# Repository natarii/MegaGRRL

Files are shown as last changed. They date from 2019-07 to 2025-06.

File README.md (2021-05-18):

MegaGRRL - Real Hardware Sega Genesis VGM Player
========
**MegaGRRL** is an ESP32-powered VGM player, playing tracks from the Sega Mega Drive/Genesis, Master System, and more on real YM2612 and SN76489 sound chips.

## Overview
MegaGRRL is a system comprised of ESP32-powered hardware to interface with original YM2612 and SN76489 sound chips, and FreeRTOS-based firmware using the ESP-IDF framework. Its playback engine is focused on high accuracy and supporting as many features of the VGM file format as possible. It is a completely standalone player, requiring no connection to a host PC. MegaGRRL OS has a fully-featured, easy to use UI, and several unique features which make it the premier hardware playback solution.

There are currently two main hardware versions. The same firmware targets both.
  * **MegaGRRL Desktop**
  * **MegaGRRL Portable** (still in development)

The MegaGRRL Desktop hardware also supports the following **MegaMods** allowing sound chips other than the YM2612/SN76489 to be used:
  * **OPNA MegaMod** - Uses the OPNA (YM2608). Can also play VGMs for OPN (YM2203) and AY-3-8910.
  * **OPL3 MegaMod** - Uses the OPL3 (YMF262). Can also play VGMs for OPL2 (YM3812) and OPL (YM3526).

This repository contains the MegaGRRL OS firmware, and includes the hardware as submodules. Use `--recursive` when cloning the repo to get the hardware files as well.

  * **esp-idf-patches/** - ESP-IDF v3.3.4 SPI master driver patches, required for build
  * **hardware/** - Hardware files for all base board versions, and MegaMods for the Desktop version
  * **firmware/** - Firmware for the ESP32
  * **utils/** - Utilities, such as for packing firmware updates

## Compiling and initial flash
  * Windows users: A complete guide is available [here](https://git.agiri.ninja/snippets/3).
  * Other platforms: MegaGRRL OS is built like a standard ESP-IDF v3.3.4 project, but some patches are required. Please see [doc/compiling.md](https://git.agiri.ninja/natalie/megagrrl/-/blob/master/doc/compiling.md) for more information.

## Updating firmware
To update to the latest firmware after your player is up and running, download the latest .mgu file for your hardware version (desktop or portable) from the [Releases page](https://git.agiri.ninja/natalie/megagrrl/-/releases) and copy it to the SD card. Launch the update from MegaGRRL's file browser.

## Obtaining VGM files
The defacto standard Genesis/Mega Drive VGM repository is [Project 2612](https://project2612.org/). Both .vgm and .vgz files are supported, but load times are shorter if using vgm. VGMs for other sound chips can be obtained from [VGMRips](https://vgmrips.net/packs/).

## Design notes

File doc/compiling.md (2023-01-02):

## Compiling and initial flash
0. If you are on Windows and flashing a MegaGRRL Desktop, a simplified guide is available [here](https://git.agiri.ninja/snippets/3). Otherwise, proceed with the instructions below.
1. Set up ESP-IDF v3.3.4 following the [Espressif documentation](https://docs.espressif.com/projects/esp-idf/en/v3.3.4/get-started/index.html).
2. Clone the repo
   - `cd ~`
   - `git clone https://git.agiri.ninja/natalie/megagrrl`
   - `cd megagrrl`
   - `git tag` <- find the latest version
   - `git checkout v0.00` <- use the latest version number here
3. Apply the patches contained in `esp-idf-patches/`.
   - `patch $IDF_PATH/components/driver/spi_master.c spi_master.c.patch`
   - `patch $IDF_PATH/components/driver/include/driver/spi_master.h spi_master.h.patch`
   - If you are on Windows and using Espressif's MSYS2 setup, you will need to install patch using `pacman -S patch`
4. Uncomment `#define FWUPDATE` in `firmware/main/hal.h`, and ensure the correct hardware version is uncommented.
5. Connect the MegaGRRL's UART to your computer. Ensure the SD card D2 pullup resistor is not populated (R999 on portable, RN2 on desktop), and no SD card is inserted.
6. Burn the 3.3 volt flash efuse using `$IDF_PATH/components/esptool_py/esptool/espefuse.py set_flash_voltage 3.3V`.
7. `make flash`. The firmware updater is now installed on the ESP32.
8. If MegaGRRL's display appears sideways and corrupted, you will need to select an alternate LCD in `hal.h`.
9. Re-comment `#define FWUPDATE`.
10. `make all`.
11. Format an SD card as FAT32, then find the `megagrrl.bin` file in `firmware/build/`, rename it to `factory.mgf`, and copy it to the root of the card.
12. Populate the SD card D2 pullup resistor.
13. Insert the card into the MegaGRRL and power it on. The firmware will now self-flash, and reboot into the OS.

Note: If the default serial device (`/dev/ttyUSB0`) doesn't work on your machine, you may need to set it manually using the `--port` option (for Python scripts) or the `ESPPORT` environment variable (for `make`). On macOS, for example, the device path may take the form of `/dev/cu.usbserial-1420` (with the Apple driver in Mojave and later) or `/dev/cu.wchusbserial1420` (with the OEM CH34x driver). On BSD systems, a path like `/dev/cuaU0` may be used.

## Development
For testing code during development, you must flash it to the correct partition. Under Linux with a standard esp-idf setup, a command such as the following will work:
`python $IDF_PATH/components/esptool_py/esptool/esptool.py --chip esp32 --port /dev/ttyUSB0 --baud 2000000 --before default_reset --after hard_reset write_flash -z --flash_mode qio --flash_freq 80m --flash_size detect 0x110000 build/megagrrl.bin`

Debugging should be done using serial (`make monitor`). JTAG is not usable due to GPIO overlap with the SD card interface.

## Generating firmware update packfiles
A script is included at `utils/megapacker.pl` to generate .mgu files from self-built .bin files. The simplest case would be to pack a new app image (i.e. built without FWUPDATE defined):

   - `perl utils/megapacker.pl --app=firmware/build/megagrrl.bin --outfile=megagrrl.mgu`

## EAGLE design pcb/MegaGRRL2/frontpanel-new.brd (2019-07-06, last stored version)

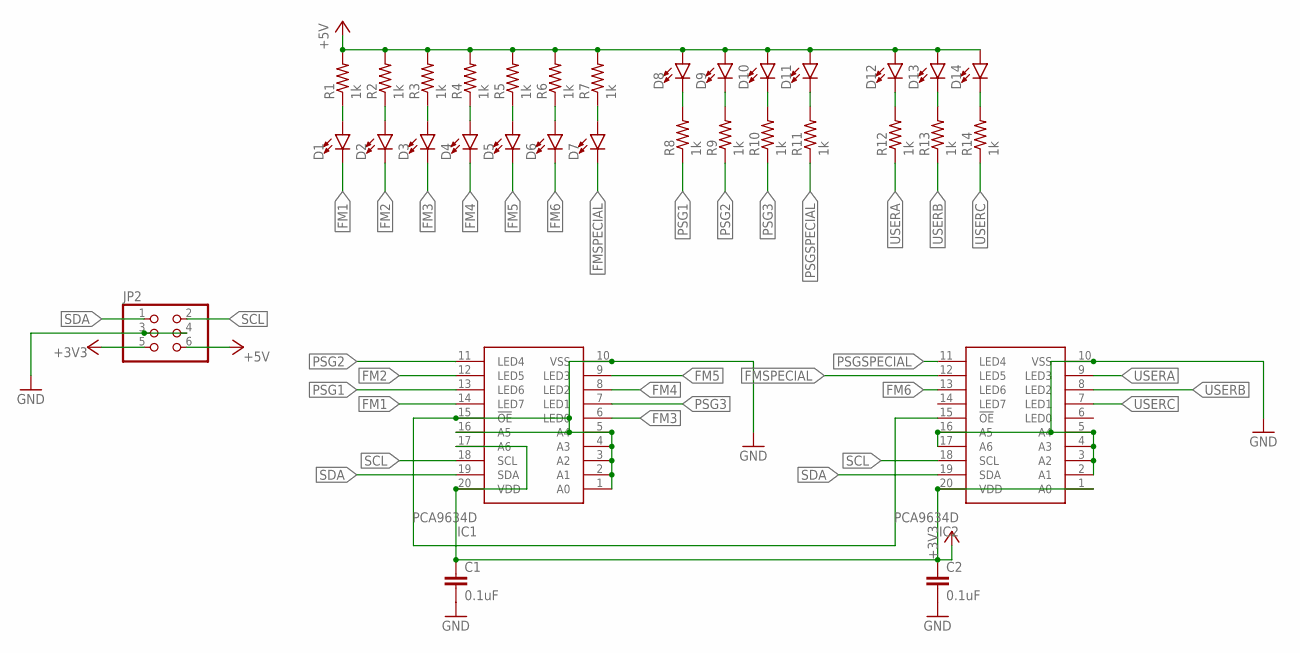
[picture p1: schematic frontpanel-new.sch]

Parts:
C1, C2: 0.1uF; C0805
D1, D2, D3, D4, D5, D6, D7, D8, D9, D10, D11, D12, D13, D14: AM2520; AM2520HOLE
IC1, IC2: PCA9634D; SOIC127P1032X265-20N
JP2: PINHD-2X3SMT; 2X03_SMT
R1, R2, R3, R4, R5, R6, R7, R8, R9, R10, R11, R12, R13, R14: 1k; R0805

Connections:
+3V3: C1.1, C2.1, IC1.17 (A6), IC1.20 (VDD), IC2.1 (A0), IC2.20 (VDD), JP2.5
+5V: D8.A, D9.A, D10.A, D11.A, D12.A, D13.A, D14.A, JP2.6, R1.2, R2.2, R3.2, R4.2, R5.2, R6.2, R7.2
FM1: D1.C, IC1.14 (LED7)
FM2: D2.C, IC1.12 (LED5)
FM3: D3.C, IC1.6 (LED0)
FM4: D4.C, IC1.8 (LED2)
FM5: D5.C, IC1.9 (LED3)
FM6: D6.C, IC2.13 (LED6)
FMSPECIAL: D7.C, IC2.12 (LED5)
GND: C1.2, C2.2, IC1.1 (A0), IC1.2 (A1), IC1.3 (A2), IC1.4 (A3), IC1.5 (A4), IC1.10 (VSS), IC1.15 (!OE), IC1.16 (A5), IC2.2 (A1), IC2.3 (A2), IC2.4 (A3), IC2.5 (A4), IC2.10 (VSS), IC2.15 (!OE), IC2.16 (A5), IC2.17 (A6), JP2.3, JP2.4
unnamed: D12.C, R12.2
unnamed: D1.A, R1.1
unnamed: D5.A, R5.1
unnamed: D3.A, R3.1
unnamed: D6.A, R6.1
unnamed: D4.A, R4.1
unnamed: D2.A, R2.1
unnamed: D7.A, R7.1
unnamed: D8.C, R8.2
unnamed: D9.C, R9.2
unnamed: D10.C, R10.2
unnamed: D11.C, R11.2
unnamed: D13.C, R13.2
unnamed: D14.C, R14.2
PSG1: IC1.13 (LED6), R8.1
PSG2: IC1.11 (LED4), R9.1
PSG3: IC1.7 (LED1), R10.1
PSGSPECIAL: IC2.11 (LED4), R11.1
SCL: IC1.18 (SCL), IC2.18 (SCL), JP2.2
SDA: IC1.19 (SDA), IC2.19 (SDA), JP2.1
USERA: IC2.9 (LED3), R12.1
USERB: IC2.8 (LED2), R13.1
USERC: IC2.7 (LED1), R14.1

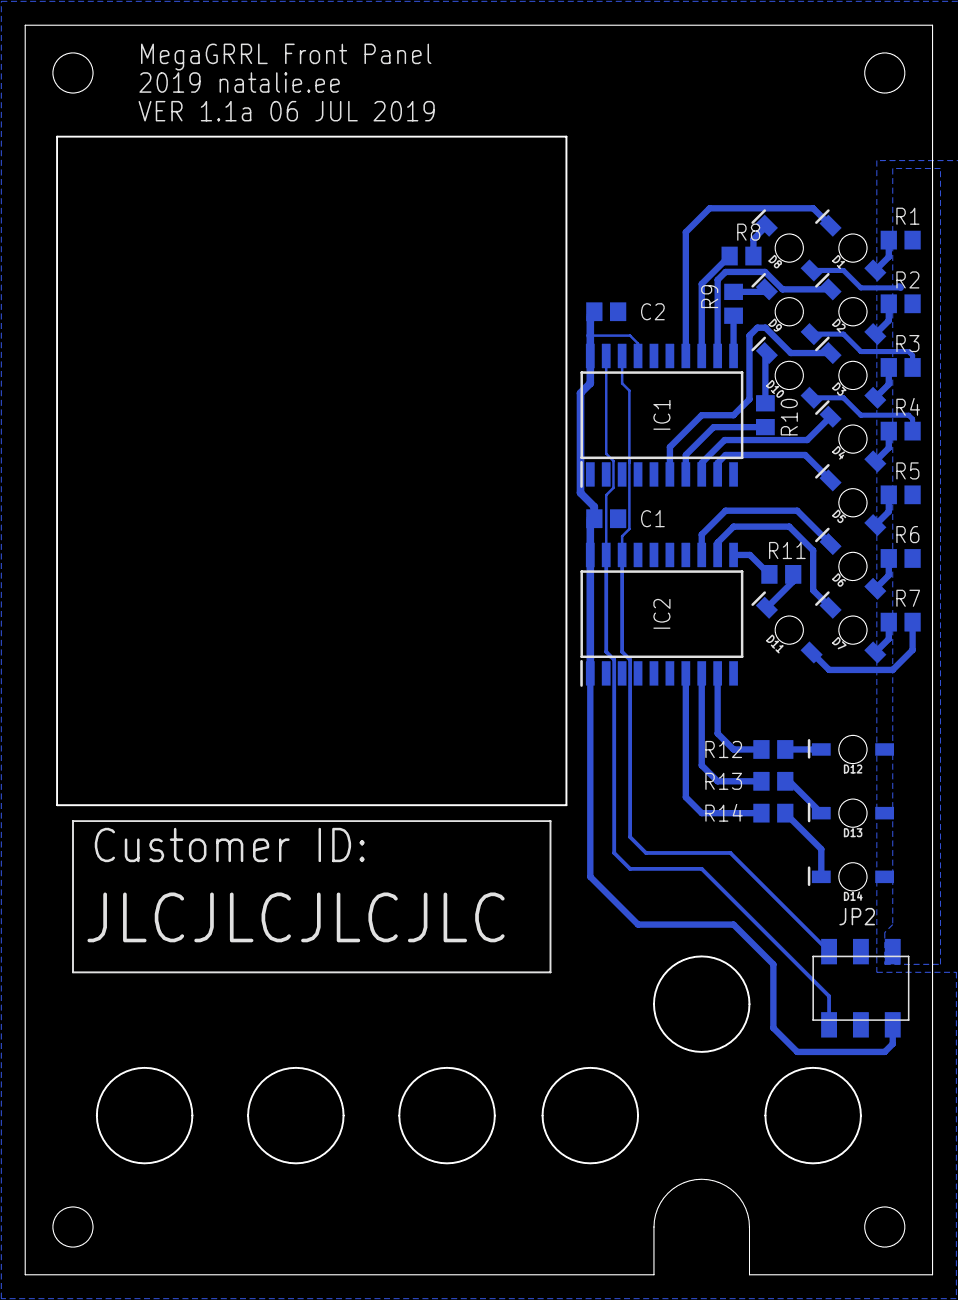
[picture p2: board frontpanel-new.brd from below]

Board: 2 copper layers, 72.4 x 99.7 mm, 33 parts (33 on the bottom side), 33 nets.

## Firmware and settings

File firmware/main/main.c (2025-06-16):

/*
    MegaGRRL source code

    Copyright (c) 2018-2024, kunoichi labs / natalie null
*/

#include "freertos/FreeRTOS.h"
#include "esp_wifi.h"
#include "esp_system.h"
#include "esp_event.h"
#include "esp_event_loop.h"
#include "nvs_flash.h"
#include "driver/gpio.h"
#include "esp_log.h"
#include "rom/rtc.h"
#include "esp_flash_partitions.h"
#include "esp_partition.h"
#include "esp_ota_ops.h"
#include "bootloader_random.h"
#include "spi_flash_mmap.h"

#include "driver.h"
#include "taskmgr.h"
#include "clk.h"
#include "sdcard.h"
#include "i2c.h"
#include "ioexp.h"
#include "lvgl.h"
#include "lcddma.h"
#include "ui.h"
#include "hal.h"
#include "leddrv.h"
#include "hspi.h"
#include "ver.h"
#include "key.h"
#include "logmgr.h"
#ifndef FWUPDATE
#include "battery.h"
#include "dacstream.h"
#include "loader.h"
#include "queue.h"
#include "player.h"
#include "channels.h"
#include "userled.h"
#include "options.h"
#endif

#ifdef HWVER_PORTABLE
LV_IMG_DECLARE(img_frame);
#elif defined HWVER_DESKTOP
LV_IMG_DECLARE(img_desktopframe);
#endif
LV_IMG_DECLARE(img_blank);
LV_IMG_DECLARE(img_lcdsd);
LV_IMG_DECLARE(img_lcdsdq);
LV_IMG_DECLARE(img_lcdhappy);
LV_IMG_DECLARE(img_lcdsad);
LV_IMG_DECLARE(img_kunoichilabs_smol);

#include <stdio.h>
#include <dirent.h>

static const char* TAG = "Main";

//LV_FONT_DECLARE(lv_font_monospace_8);

lv_obj_t *frame;
lv_obj_t *progress;
lv_style_t progressstyle;
lv_obj_t *lcd;
#define MAIN_PROGRESS_MAX 14
uint8_t progressval = 0;
#define MAIN_PROGRESS_UPDATE LcdDma_Mutex_Take(pdMS_TO_TICKS(1000)); lv_obj_set_width(progress, main_map(++progressval,0,MAIN_PROGRESS_MAX,0,50)); LcdDma_Mutex_Give(); vTaskDelay(2);
lv_obj_t * textarea;
lv_style_t textarea_style;
static IRAM_ATTR lv_obj_t *mainbg;
static lv_style_t mainbg_style;

#ifdef FWUPDATE
uint8_t buf[10240];
#endif

uint32_t main_map(uint32_t x, uint32_t in_min, uint32_t in_max, uint32_t out_min, uint32_t out_max) {
  return (x - in_min) * (out_max - out_min) / (in_max - in_min) + out_min;
}

void crash() {
    ESP_LOGE(TAG, "CRASHING !!");
    LcdDma_Mutex_Take(pdMS_TO_TICKS(1000));
    textarea_style.body.main_color = LV_COLOR_MAKE(255,0,0);
    textarea_style.body.grad_color = LV_COLOR_MAKE(255,0,0);
    textarea_style.text.color = LV_COLOR_MAKE(255,255,255);
    lv_obj_report_style_mod(&textarea_style);
    lv_obj_set_hidden(progress, true);
    lv_img_set_src(lcd, &img_lcdsad);
    LcdDma_Mutex_Give();
    for (uint8_t i=0;i<5;i++) vTaskDelay(pdMS_TO_TICKS(1000));
    for (uint8_t i=0;i<5;i++) {
        LcdDma_Mutex_Take(pdMS_TO_TICKS(1000));
        lv_obj_set_hidden(textarea, false);
        lv_ta_add_text(textarea, ".");
        LcdDma_Mutex_Give();
        uint32_t s = xthal_get_ccount();
        while (xthal_get_ccount() - s <= 1000*240000) {
            vTaskDelay(pdMS_TO_TICKS(10));
        }
    }
    IoExp_PowerControl(false);
    vTaskDelay(pdMS_TO_TICKS(500));
    //if we get here, either usb power is present or the user is holding the power button. either way, reboot...
    esp_restart();
}

void crash_sd(uint8_t reason) {
    lv_obj_t *rlabel;
    lv_style_t rlabel_style;
    lv_style_copy(&rlabel_style, &lv_style_plain);
    rlabel_style.text.color = LV_COLOR_MAKE(255,255,255);
    //rlabel_style.text.font = &lv_font_monospace_8;
    LcdDma_Mutex_Take(pdMS_TO_TICKS(1000));
    lv_obj_set_hidden(progress, true);
    rlabel = lv_label_create(mainbg, NULL);
    lv_label_set_long_mode(rlabel, LV_LABEL_LONG_SROLL);
    lv_obj_set_width(rlabel, 240);
    lv_label_set_align(rlabel, LV_LABEL_ALIGN_CENTER);
    lv_label_set_style(rlabel, LV_LABEL_STYLE_MAIN, &rlabel_style);
    if (reason == 1) {
        lv_label_set_static_text(rlabel, "No card inserted");
    } else if (reason == 2) {
        lv_label_set_static_text(rlabel, "No FAT32 filesystem found");
    } else if (reason == 3) {
        lv_label_set_static_text(rlabel, "Card is write-protected");
    } else {
        lv_label_set_static_text(rlabel, "Unknown card error");
    }
    lv_obj_set_pos(rlabel, 0, 126+67+10);
    LcdDma_Mutex_Give();
    for (uint8_t i=0;i<10;i++) {
        LcdDma_Mutex_Take(pdMS_TO_TICKS(1000));
        lv_img_set_src(lcd, &img_lcdsdq);
        LcdDma_Mutex_Give();
        vTaskDelay(pdMS_TO_TICKS(500));
        LcdDma_Mutex_Take(pdMS_TO_TICKS(1000));
        lv_img_set_src(lcd, &img_lcdsd);
        LcdDma_Mutex_Give();
        vTaskDelay(pdMS_TO_TICKS(500));
    }
    IoExp_PowerControl(false);
    vTaskDelay(pdMS_TO_TICKS(500));
    esp_restart();
}

void checkcore() {
    LcdDma_Mutex_Take(pdMS_TO_TICKS(1000));
    LcdDma_AltMode = true;
    LcdDma_Mutex_Give();
    ESP_LOGI(TAG, "looking for core...");
    const esp_partition_t *corepart;
    corepart = esp_partition_find_first(ESP_PARTITION_TYPE_DATA, ESP_PARTITION_SUBTYPE_DATA_COREDUMP, NULL);
    if (corepart) {
        uint8_t *core;
        spi_flash_mmap_handle_t handle;
        esp_err_t err;
        err = esp_partition_mmap(corepart, 0, corepart->size, SPI_FLASH_MMAP_DATA, (const void**)&core, &handle);
        if (err == ESP_OK) {
            ESP_LOGI(TAG, "core mmap ok");
            for (uint32_t i=0;i<corepart->size;i++) {
                if (*(core+i) != 0xff) {
                    ESP_LOGI(TAG, "there's a dump here, first byte at %d, copying it to sdcard", i);
                    LcdDma_Mutex_Take(pdMS_TO_TICKS(1000));
                    lv_obj_set_hidden(textarea, false);
                    lv_ta_add_text(textarea, "Core dump found!\nCopying core to card...\n");
                    LcdDma_Mutex_Give();
                    vTaskDelay(pdMS_TO_TICKS(500));
                    FILE *f;
                    f = fopen("/sd/.mega/core.bin", "w");
                    fwrite(core, corepart->size, 1, f);
                    fclose(f);
                    ESP_LOGI(TAG, "erasing core part");
                    LcdDma_Mutex_Take(pdMS_TO_TICKS(1000));
                    lv_ta_add_text(textarea, "Removing core from flash...\n");
                    LcdDma_Mutex_Give();
                    vTaskDelay(pdMS_TO_TICKS(100));
                    spi_flash_munmap(handle);
                    err = esp_partition_erase_range(corepart, 0, corepart->size);
                    if (err != ESP_OK) {
                        ESP_LOGE(TAG, "core part erase failed %d", err);
                        LcdDma_Mutex_Take(pdMS_TO_TICKS(1000));
                        lv_ta_add_text(textarea, "Flash erase failed !!\n");
                        LcdDma_Mutex_Give();
                        vTaskDelay(pdMS_TO_TICKS(3000));
                    }
                    LcdDma_Mutex_Take(pdMS_TO_TICKS(1000));
                    lv_obj_set_hidden(textarea, true);
                    LcdDma_AltMode = false;
                    LcdDma_Mutex_Give();
                    return;
                }
            }
            ESP_LOGI(TAG, "no core found");
        } else {
            ESP_LOGI(TAG, "failed to mmap core !!");
        }
    } else {
        ESP_LOGI(TAG, "no core partition found");
    }
    LcdDma_Mutex_Take(pdMS_TO_TICKS(1000));
    LcdDma_AltMode = false;
    LcdDma_Mutex_Give();
}

void app_main(void) {
    assert(configUSE_16_BIT_TICKS == 0);
    esp_log_level_set("*", ESP_LOG_DEBUG);
    //uint8_t r = rtc_get_reset_reason(0);

    #ifdef FWUPDATE
    ESP_LOGI(TAG, "MegaGRRL OS Updater");
    #else
    ESP_LOGI(TAG, "MegaGRRL boot");
    #endif
    ESP_LOGI(TAG, "Copyright (c) 2018-2019, kunoichi labs / natalie null");
    ESP_LOGI(TAG, "https://kunoichilabs.dev");
    ESP_LOGI(TAG, "Compiled on %s at %s", __DATE__, __TIME__);
    #if defined HWVER_PORTABLE
    ESP_LOGI(TAG, "For hardware version: Portable");
    #elif defined HWVER_DESKTOP
    ESP_LOGI(TAG, "For hardware version: Desktop");
    #endif
        
    bool setup_ret = false;

    //this is only in here because the chips use more power when not being clocked
    ESP_LOGI(TAG, "Bring up FM clock...");
    Clk_CreateMutex();
    Clk_Set(CLK_FM, 7670453);

    bootloader_random_enable(); //do this now. it also makes the i2s clock stuff start working...

    ESP_LOGI(TAG, "Setting up driver...");
    Driver_Setup();

    ESP_LOGI(TAG, "Detecting mods...");
    Driver_ModDetect();
    switch (Driver_DetectedMod) {
        case MEGAMOD_NONE:
            ESP_LOGI(TAG, "No mod detected, assuming DCSG");
            Clk_Set(CLK_DCSG, 3579545);
            break;
        case MEGAMOD_OPLLDCSG:
            ESP_LOGI(TAG, "OPLL+DCSG detected, switching FM clock to DCSG");
            Clk_Set(CLK_FM, 3579545);
            break;
        case MEGAMOD_OPL3:
            ESP_LOGI(TAG, "OPL3 detected, switching FM clock to OPL3");
            Clk_Set(CLK_FM, 14318180);
            break;
        case MEGAMOD_OPNA:
            ESP_LOGI(TAG, "OPNA detected, switching FM clock to OPNA");
            Clk_Set(CLK_FM, 8000000);
            break;
        case MEGAMOD_OPM:
            ESP_LOGI(TAG, "OPM detected, switching FM clock to OPM");
            Clk_Set(CLK_FM, 3579545);
            break;
        case MEGAMOD_OPNOPLL:
            ESP_LOGI(TAG, "OPN+OPLL detected, switching FM clock to OPN");
            Clk_Set(CLK_FM, 4000000);
            break;
        case MEGAMOD_2XOPN:
            ESP_LOGI(TAG, "2xOPN detected, switching FM clock to OPN");
            Clk_Set(CLK_FM, 4000000);
            break;
        default:
            ESP_LOGE(TAG, "Unsupported mod (ID %d)", Driver_DetectedMod);
            break;
    }

    ESP_LOGI(TAG, "Driver reset no.2");
    Driver_ResetChips(true);

    ESP_LOGI(TAG, "Clear I2C...");
    uint8_t i2cclearresult = I2cMgr_Clear();

    ESP_LOGI(TAG, "Init I2C...");
    bool I2cUp = I2cMgr_Setup();

    ESP_LOGI(TAG, "Init IoExp...");
    bool IoUp = IoExp_Setup();

    ESP_LOGI(TAG, "Init hspi...");
    Hspi_Setup();

    #ifndef FWUPDATE
    #ifdef HWVER_PORTABLE
    //turn off our own power. if we crashed previously, let's not just auto-reboot...
    ESP_LOGI(TAG, "Try poweroff...");
    IoExp_PowerControl(false);
    vTaskDelay(pdMS_TO_TICKS(250));
    //if we're still running at this point, either the user is holding the power button, or usb power is connected, so continue with booting...
    //it's also possible the ioexpander is very borked
    #endif
    #endif

    ESP_LOGI(TAG, "Early LcdDma setup... let's hope this doesn't fail !!");
    LcdDma_Setup();

    ESP_LOGI(TAG, "Early UI setup... let's hope this doesn't fail !!");
    Ui_EarlySetup();

    #ifdef HWVER_PORTABLE
    IoExp_PowerControl(true);
    IoExp_BacklightControl(true);
    #endif

    LcdDma_Mutex_Take(pdMS_TO_TICKS(1000));

    lv_style_copy(&mainbg_style, &lv_style_plain);
    mainbg_style.body.main_color = LV_COLOR_MAKE(0,0,0);
    mainbg_style.body.grad_color = LV_COLOR_MAKE(0,0,0);
    mainbg = lv_obj_create(lv_layer_top(), NULL);
    lv_obj_set_style(mainbg, &mainbg_style);
    lv_obj_set_pos(mainbg, 0, 0);
    lv_obj_set_size(mainbg, 240, 320);

    frame = lv_img_create(mainbg, NULL);
    #ifdef HWVER_PORTABLE
    lv_img_set_src(frame, &img_frame);
    lv_obj_set_pos(frame, 95, 126);
    #elif defined HWVER_DESKTOP
    lv_img_set_src(frame, &img_desktopframe);
    lv_obj_set_pos(frame, 86, 126);
    #endif

    lcd = lv_img_create(mainbg, NULL);
    lv_img_set_src(lcd, &img_blank);
    #ifdef HWVER_PORTABLE
    lv_obj_set_pos(lcd, 95+21, 126+8);
    #elif defined HWVER_DESKTOP
    lv_obj_set_pos(lcd, 86+22, 126+5);
    #endif

    static lv_obj_t *kl;
    kl = lv_img_create(mainbg, NULL);
    lv_img_set_src(kl, &img_kunoichilabs_smol);
    lv_obj_set_pos(kl, 120 - (157/2), 250);

    lv_style_copy(&progressstyle, &lv_style_plain);
    progressstyle.body.main_color = LV_COLOR_MAKE(255,255,255);
    progressstyle.body.grad_color = LV_COLOR_MAKE(255,255,255);

    progress = lv_obj_create(mainbg, NULL);
    lv_obj_set_height(progress, 10);
    lv_obj_set_width(progress, 0);
    lv_obj_set_pos(progress, 95, 126+67+10);
    lv_obj_set_style(progress, &progressstyle);

    lv_style_copy(&textarea_style, &lv_style_plain);
    textarea_style.text.color = LV_COLOR_MAKE(0,0,0);
    textarea_style.body.main_color = LV_COLOR_MAKE(0x74,0xd7,0xec);
    textarea_style.body.grad_color = LV_COLOR_MAKE(0xff,0xaf,0xc7);
    //textarea_style.text.font = &lv_font_monospace_8;

    textarea = lv_ta_create(mainbg, NULL);
    lv_obj_set_size(textarea, 240, 320);
    lv_obj_set_pos(textarea, 0, 0);
    lv_ta_set_style(textarea, LV_TA_STYLE_BG, &textarea_style);
    lv_ta_set_cursor_type(textarea, LV_CURSOR_NONE);
    lv_ta_set_cursor_pos(textarea, 0);
    if ((IoExp_PowerOnKeys & (1<<KEY_B)) == 0) lv_obj_set_hidden(textarea, true);

    #ifdef FWUPDATE
    lv_ta_set_text(textarea, "MegaGRRL\nby kunoichi labs\n\nOS Updater\n\n");
    #else
    lv_ta_set_text(textarea, "MegaGRRL\nby kunoichi labs\n\nBoot\n");
    #endif

    #if defined HWVER_PORTABLE
    lv_ta_add_text(textarea, "Hw VER: Portable");
    #elif defined HWVER_DESKTOP
    lv_ta_add_text(textarea, "Hw VER: Desktop");
    #endif
    lv_ta_add_text(textarea, "\nFw VER: ");
    lv_ta_add_text(textarea, FWVER);
    lv_ta_add_text(textarea, "\n");

    LcdDma_Mutex_Give();

    if (!I2cUp) {
        LcdDma_Mutex_Take(pdMS_TO_TICKS(1000));
        lv_ta_add_text(textarea, "I2C init failed !!\n");
        if (i2cclearresult == 1) {
            lv_ta_add_text(textarea, "SDA line stuck low?\n");
        } else if (i2cclearresult == 2) {
            lv_ta_add_text(textarea, "SCL line stuck low?\n");
        } else if (i2cclearresult == 3) {
            lv_ta_add_text(textarea, "SCL and SDA lines shorted?\n");
        }
        LcdDma_Mutex_Give();
        crash();
    }
    MAIN_PROGRESS_UPDATE;
    if (!IoUp) {
        LcdDma_Mutex_Take(pdMS_TO_TICKS(1000));
        lv_ta_add_text(textarea, "IO init failed !!\n");
        if (i2cclearresult == 1) {
            lv_ta_add_text(textarea, "SDA line stuck low?\n");
        } else if (i2cclearresult == 2) {
            lv_ta_add_text(textarea, "SCL line stuck low?\n");
        } else if (i2cclearresult == 3) {
            lv_ta_add_text(textarea, "SCL and SDA lines shorted?\n");
        }
        LcdDma_Mutex_Give();
        crash();
    }
    MAIN_PROGRESS_UPDATE;

    LcdDma_Mutex_Take(pdMS_TO_TICKS(1000));
    lv_ta_add_text(textarea, "Setting up LedDrv... ");
    LcdDma_Mutex_Give();
    setup_ret = LedDrv_Setup();
    if (setup_ret) {
        LcdDma_Mutex_Take(pdMS_TO_TICKS(1000));
        lv_ta_add_text(textarea, "ok\n");
        LcdDma_Mutex_Give();
        MAIN_PROGRESS_UPDATE;
    } else {
        LcdDma_Mutex_Take(pdMS_TO_TICKS(1000));
        lv_ta_add_text(textarea, "failed !!\n");
        LcdDma_Mutex_Give();
        //crash();
    }

    LcdDma_Mutex_Take(pdMS_TO_TICKS(1000));
    lv_ta_add_text(textarea, "Setting up Sdcard... ");
    LcdDma_Mutex_Give();
    uint8_t card_setup_ret = Sdcard_Setup();
    if (card_setup_ret == 0) {
        LcdDma_Mutex_Take(pdMS_TO_TICKS(1000));
        lv_ta_add_text(textarea, "ok\n");
        LcdDma_Mutex_Give();
        MAIN_PROGRESS_UPDATE;
    } else {
        LcdDma_Mutex_Take(pdMS_TO_TICKS(1000));
        lv_ta_add_text(textarea, "failed !!\n");
        LcdDma_Mutex_Give();
        crash_sd(card_setup_ret);
    }

    LcdDma_Mutex_Take(pdMS_TO_TICKS(1000));
    lv_ta_add_text(textarea, "Checking for core...\n");
    LcdDma_Mutex_Give();
    checkcore();
    MAIN_PROGRESS_UPDATE;

    #ifdef FWUPDATE
    LcdDma_Mutex_Take(pdMS_TO_TICKS(1000));
    vTaskDelay(pdMS_TO_TICKS(500));
    LcdDma_AltMode = true;
    lv_obj_set_hidden(textarea, false);
    lv_obj_set_hidden(frame, true);
    lv_obj_set_hidden(lcd, true);
    lv_obj_set_hidden(progress, true);
    lv_ta_add_text(textarea, "Looking for update file...\n");
    LcdDma_Mutex_Give();
    FILE *fw;
    fw = fopen("/sd/recovery.mgf", "r");
    if (fw == NULL) fw = fopen("/sd/.mega/firmware.mgf", "r");
    if (fw == NULL) fw = fopen("/sd/factory.mgf", "r");
    if (fw == NULL) {
        LcdDma_Mutex_Take(pdMS_TO_TICKS(1000));
        lv_ta_add_text(textarea, "No update file found!");
        LcdDma_Mutex_Give();
        crash();
    }

    //ready to flash
    LcdDma_Mutex_Take(pdMS_TO_TICKS(1000));
    lv_ta_add_text(textarea, "\nDO NOT REMOVE SD CARD\nDO NOT POWER OFF\n\n");
    LcdDma_Mutex_Give();
    vTaskDelay(pdMS_TO_TICKS(5000));
    LcdDma_Mutex_Take(pdMS_TO_TICKS(1000));
    lv_ta_add_text(textarea, "Locating OS partition\n");
    LcdDma_Mutex_Give();
    const esp_partition_t *partition;
    partition = esp_partition_find_first(ESP_PARTITION_TYPE_APP, ESP_PARTITION_SUBTYPE_APP_OTA_1, NULL);
    uint8_t *app;
    spi_flash_mmap_handle_t mmaphandle;
    vTaskDelay(pdMS_TO_TICKS(500));
    LcdDma_Mutex_Take(pdMS_TO_TICKS(1000));
    lv_ta_add_text(textarea, "Backing up...\n");
    LcdDma_Mutex_Give();
    esp_partition_mmap(partition, 0, partition->size, SPI_FLASH_MMAP_DATA, (const void**)&app, &mmaphandle);
    FILE *f = fopen("/sd/.mega/backup_1.bin", "w");
    fwrite(app, partition->size, 1, f);
    fclose(f);
    spi_flash_munmap(mmaphandle);
    esp_ota_handle_t update = 0;
    vTaskDelay(pdMS_TO_TICKS(500));
    LcdDma_Mutex_Take(pdMS_TO_TICKS(1000));
    lv_ta_add_text(textarea, "Starting update\n");
    LcdDma_Mutex_Give();
    esp_ota_begin(partition, OTA_SIZE_UNKNOWN, &update);
    LcdDma_Mutex_Take(pdMS_TO_TICKS(1000));
    lv_ta_add_text(textarea, "Flashing");
    LcdDma_Mutex_Give();
    while (!feof(fw)) {
        uint16_t read;
        read = fread(&buf[0], sizeof(uint8_t), sizeof(buf), fw);
        esp_ota_write(update, &buf[0], read);
        LcdDma_Mutex_Take(pdMS_TO_TICKS(1000));
        lv_ta_add_text(textarea, ".");
        LcdDma_Mutex_Give();
        vTaskDelay(2);
    }
    fclose(fw);

    LcdDma_Mutex_Take(pdMS_TO_TICKS(1000));
    lv_ta_add_text(textarea, "\nRemoving update file\n");
    LcdDma_Mutex_Give();
    vTaskDelay(2);
    rename("/sd/.mega/firmware.mgf", "/sd/.mega/backup_n.mgf");
    rename("/sd/.mega/factory.mgf", "/sd/.mega/backup_f.mgf");
    rename("/sd/.mega/recovery.mgf", "/sd/.mega/backup_r.mgf");

    LcdDma_Mutex_Take(pdMS_TO_TICKS(1000));
    lv_ta_add_text(textarea, "Finishing update\n");
    LcdDma_Mutex_Give();
    vTaskDelay(2);
    esp_ota_end(update);

    LcdDma_Mutex_Take(pdMS_TO_TICKS(1000));
    lv_ta_add_text(textarea, "Setting boot partition\n");
    LcdDma_Mutex_Give();
    vTaskDelay(2);
    esp_ota_set_boot_partition(partition);

    LcdDma_Mutex_Take(pdMS_TO_TICKS(1000));
    //lv_ta_set_text(textarea, "Rebooting");
    lv_obj_set_hidden(textarea, true);
    lv_obj_set_hidden(frame, false);
    lv_obj_set_hidden(lcd, false);
    lv_img_set_src(lcd, &img_lcdhappy);
    LcdDma_Mutex_Give();

    vTaskDelay(pdMS_TO_TICKS(5000));

    esp_restart();
    #endif

    #ifndef FWUPDATE

    LcdDma_Mutex_Take(pdMS_TO_TICKS(1000));
    lv_ta_add_text(textarea, "Setting up KeyMgr... ");
    LcdDma_Mutex_Give();
    setup_ret = KeyMgr_Setup();
    if (setup_ret) {
        LcdDma_Mutex_Take(pdMS_TO_TICKS(1000));
        lv_ta_add_text(textarea, "ok\n");
        LcdDma_Mutex_Give();
        MAIN_PROGRESS_UPDATE;
    } else {
        LcdDma_Mutex_Take(pdMS_TO_TICKS(1000));
        lv_ta_add_text(textarea, "failed !!\n");
        LcdDma_Mutex_Give();
        crash();
    }

    LcdDma_Mutex_Take(pdMS_TO_TICKS(1000));
    lv_ta_add_text(textarea, "Setting up OptionsMgr...");
    LcdDma_Mutex_Give();
    OptionsMgr_Setup();
    MAIN_PROGRESS_UPDATE;
    if ((IoExp_PowerOnKeys & (1<<KEY_LEFT)) && (IoExp_PowerOnKeys & (1<<KEY_RIGHT)) && (IoExp_PowerOnKeys & (1<<KEY_A))) {
        ESP_LOGE(TAG, "/!\\ SETTING LOGLEVEL TO ESP_LOG_INFO! /!\\");
        logmgr_loglevel = 1;
        logmgr_update_loglevel();
        ESP_LOGI(TAG, "Queueing options save");
        OptionsMgr_Touch();
    }

    LcdDma_Mutex_Take(pdMS_TO_TICKS(1000));
    lv_ta_add_text(textarea, "Setting up ChannelMgr... ");
    LcdDma_Mutex_Give();
    setup_ret = ChannelMgr_Setup();
    if (setup_ret) {
        LcdDma_Mutex_Take(pdMS_TO_TICKS(1000));
        lv_ta_add_text(textarea, "ok\n");
        LcdDma_Mutex_Give();
        MAIN_PROGRESS_UPDATE;
    } else {
        LcdDma_Mutex_Take(pdMS_TO_TICKS(1000));
        lv_ta_add_text(textarea, "failed !!\n");
        LcdDma_Mutex_Give();
        crash();
    }

    LcdDma_Mutex_Take(pdMS_TO_TICKS(1000));
    lv_ta_add_text(textarea, "Setting up UserLedMgr... ");
    LcdDma_Mutex_Give();
    setup_ret = UserLedMgr_Setup();
    if (setup_ret) {
        LcdDma_Mutex_Take(pdMS_TO_TICKS(1000));
        lv_ta_add_text(textarea, "ok\n");
        LcdDma_Mutex_Give();
        MAIN_PROGRESS_UPDATE;
    } else {
        LcdDma_Mutex_Take(pdMS_TO_TICKS(1000));
        lv_ta_add_text(textarea, "failed !!\n");
        LcdDma_Mutex_Give();
        crash();
    }

    LcdDma_Mutex_Take(pdMS_TO_TICKS(1000));
    lv_ta_add_text(textarea, "Setting up BatteryMgr... ");
    LcdDma_Mutex_Give();
    setup_ret = BatteryMgr_Setup();
    if (setup_ret) {
        LcdDma_Mutex_Take(pdMS_TO_TICKS(1000));
        lv_ta_add_text(textarea, "ok\n");
        LcdDma_Mutex_Give();
        MAIN_PROGRESS_UPDATE;
    } else {
        LcdDma_Mutex_Take(pdMS_TO_TICKS(1000));
        lv_ta_add_text(textarea, "failed !!\n");
        LcdDma_Mutex_Give();
        crash();
    }

    LcdDma_Mutex_Take(pdMS_TO_TICKS(1000));
    lv_ta_add_text(textarea, "Setting up DacStream... ");
    LcdDma_Mutex_Give();
    setup_ret = DacStream_Setup();
    if (setup_ret) {
        LcdDma_Mutex_Take(pdMS_TO_TICKS(1000));
        lv_ta_add_text(textarea, "ok\n");
        LcdDma_Mutex_Give();
        MAIN_PROGRESS_UPDATE;
    } else {
        LcdDma_Mutex_Take(pdMS_TO_TICKS(1000));
        lv_ta_add_text(textarea, "failed !!\n");
        LcdDma_Mutex_Give();
        crash();
    }
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

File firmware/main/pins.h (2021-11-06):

#ifndef AGR_PINS_H
#define AGR_PINS_H

#define PIN_DRIVER_SHCLK    19
#define PIN_DRIVER_DATA     23
#define PIN_DRIVER_SHSTO    18

#define PIN_I2C_CLK         16
#define PIN_I2C_DATA        17

#define PIN_IOEXP_INT       35

#define PIN_BAT_SENSE       34
#define PIN_BAT_SENSE_EN    5

#define PIN_DISP_DC         22
#define PIN_DISP_CS         21
#define PIN_DISP_SCK        32
#define PIN_DISP_MOSI       27

#define PIN_CLK_FM          5
#define PIN_CLK_DCSG         33

#endif

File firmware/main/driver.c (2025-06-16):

#include "driver.h"
#include "driver/gpio.h"
#include "xtensa/core-macros.h"
#include "mallocs.h"
#include "esp_log.h"
#include "driver/spi_master.h"
#include <string.h>
#include "esp_pm.h"
#include "vgm.h"
#include "pins.h"
#include "dacstream.h"
#include "channels.h"
#include "hal.h"
#include "driver/gpio.h"
#include "loader.h"
#include "player.h"
#include "clk.h"
#include "hal/spi_ll.h"

static const char* TAG = "Driver";

#define DRIVER_CLOCK_RATE 240000000 //clock rate of cpu while in playback
#define DRIVER_VGM_SAMPLE_RATE 44100
#define DRIVER_CYCLES_PER_SAMPLE (DRIVER_CLOCK_RATE/DRIVER_VGM_SAMPLE_RATE)

#if defined HWVER_PORTABLE
#define SR_CONTROL      0
#define SR_DATABUS      1
#define SR_BIT_DCSG_CS   0x01 // DCSG /CS
#define SR_BIT_WR       0x04 // /WR
#define SR_BIT_FM_CS    0x20 // FM /CS
#define SR_BIT_A0       0x08 // A0
#define SR_BIT_A1       0x10 // A1
#define SR_BIT_IC       0x02 // /IC
uint8_t Driver_SrBuf[2] = {0xff & ~SR_BIT_IC,0x00};
#elif defined HWVER_DESKTOP
#define SR_CONTROL      1
#define SR_DATABUS      0
#define SR_BIT_DCSG_CS   0x40 // DCSG /CS
#define SR_BIT_WR       0x20 // /WR
#define SR_BIT_FM_CS    0x80 // FM /CS
#define SR_BIT_A0       0x08 // A0
#define SR_BIT_A1       0x04 // A1
#define SR_BIT_IC       0x10 // /IC
uint8_t Driver_SrBuf[2] = {0x00,0xff & ~SR_BIT_IC};
#endif

static portMUX_TYPE mux;

MegaStreamContext_t Driver_CommandStream; //queue of incoming vgm data
MegaStreamContext_t Driver_PcmStream; //queue of attached pcm data (if any)
EventGroupHandle_t Driver_CommandEvents; //driver status flags
EventGroupHandle_t Driver_StreamEvents; //queue status flags
uint8_t *Driver_CommandStreamBuf;
uint8_t Driver_PcmBuf[DACSTREAM_BUF_SIZE*DACSTREAM_PRE_COUNT];

volatile IRAM_ATTR uint32_t Driver_CpuPeriod = 0;
volatile IRAM_ATTR uint32_t Driver_CpuUsageVgm = 0;
volatile IRAM_ATTR uint32_t Driver_CpuUsageDs = 0;
volatile bool Driver_WroteFm = false;
volatile bool Driver_WroteDcsg = false;

volatile bool Driver_AssumeSegaDcsg = true;
volatile bool Driver_MitigateVgmTrim = true;
volatile uint8_t Driver_VgmDcsgSrWidth = 16;
volatile bool Driver_VgmDcsgSpecialFreq0 = true; //true = sega

volatile MegaMod_t Driver_DetectedMod = MEGAMOD_NONE;

//we abuse the esp32's spi hardware to drive the shift registers
spi_bus_config_t Driver_SpiBusConfig = {
    .miso_io_num=-1,
    .mosi_io_num=PIN_DRIVER_DATA,
    .sclk_io_num=PIN_DRIVER_SHCLK,
    .quadwp_io_num=-1,
    .quadhd_io_num=-1,
};
spi_device_interface_config_t Driver_SpiDeviceConfig = {
    .clock_speed_hz=26600000, /*incredibly loud green hill zone music plays*/
    .mode=0,
    .spics_io_num=PIN_DRIVER_SHSTO,
    .queue_size=10,
    //.flags = SPI_DEVICE_NO_DUMMY
};
spi_device_handle_t Driver_SpiDevice;

//vgm / 2612 pcm stuff
IRAM_ATTR uint32_t Driver_Sample = 0;     //current sample number
IRAM_ATTR uint32_t Driver_Sample_Ds = 0;  //current sample number for dacstreams
uint64_t Driver_Cycle = 0;      //current cycle number
uint64_t Driver_Cycle_Ds = 0;   //current cycle number for dacstreams
IRAM_ATTR int32_t Driver_Slip = 0; //originally intended as a sample counter, currently only used as a flag.
IRAM_ATTR uint32_t Driver_Cc = 0;         //current cycle from the api - just keep it off the stack
IRAM_ATTR uint32_t Driver_LastCc = 0;     //copy of the above var
IRAM_ATTR uint32_t Driver_NextSample = 0; //sample number at which the next command needs to be run
IRAM_ATTR uint32_t Driver_ICycle = 0;
uint8_t Driver_FmAlgo[6] = {0,0,0,0,0,0};
volatile bool Driver_FirstWait = true;
uint8_t Driver_FmPans[6] = {0b11000000,0b11000000,0b11000000,0b11000000,0b11000000,0b11000000};
IRAM_ATTR uint32_t Driver_PauseSample = 0; //sample no before stop
IRAM_ATTR uint32_t Driver_PauseSample_Ds = 0; //sample no before stop for dacstreams
uint8_t Driver_DcsgAttenuation[4] = {0b10011111, 0b10111111, 0b11011111, 0b11111111};
bool Driver_NoLeds = false;
bool Driver_DcsgNoisePeriodic = false;
bool Driver_DcsgNoiseSourceCh3 = false;
static uint32_t dcsg_freq[3] = {0,0,0};
static uint8_t dcsg_latched_ch = 0;

//dacstream specific
IRAM_ATTR uint32_t DacStreamSeq = 0;              //sequence no of the current stream
IRAM_ATTR uint32_t DacStreamLastSeqPlayed = 0;    //last seq successfully played
uint8_t DacStreamId = 0;                //index of the currently playing dacstream. should maybe consider using a pointer to the queue instead of keeping this around
bool DacStreamActive = false;           //actively playing a stream?
IRAM_ATTR uint32_t DacStreamSampleRate = 0;       //stream current sample rate
uint8_t DacStreamPort = 0;              //chip port to write to
uint8_t DacStreamCommand = 0;           //chip command to use
IRAM_ATTR uint32_t DacStreamSamplesPlayed = 0;    //how many samples played so far
uint8_t DacStreamLengthMode = 0;
IRAM_ATTR uint32_t DacStreamDataLength = 0;
bool DacStreamFailed = false;

volatile uint8_t Driver_FmMask = 0b01111111;
volatile uint8_t Driver_DcsgMask = 0b00001111;
uint8_t Driver_DacEn = 0;
volatile bool Driver_ForceMono = false;
uint8_t Driver_Opna_AdpcmConfig = 0b11000000; //todo verify in emu? 
uint8_t Driver_Opna_RhythmConfig[6] = {0b11000000,0b11000000,0b11000000,0b11000000,0b11000000,0b11000000}; //todo verify in emu
uint8_t Driver_Opna_SsgConfig = 0b00111111; //todo verify in emu
uint8_t Driver_Opna_SsgLevel[3] = {0,0,0}; //todo verify in emu

volatile IRAM_ATTR uint32_t Driver_Opna_PcmUploadId = 0;
volatile bool Driver_Opna_PcmUpload = false;
FILE *Driver_Opna_PcmUploadFile = NULL;
volatile int16_t Driver_SpeedMult = 0;

static uint8_t TLs[4*6];
static uint8_t RhythmTL = 0;
static uint8_t AdpcmLevel = 0;
static const uint8_t OperatorMap[4] = {0,2,1,3};
static IRAM_ATTR uint32_t FadePos = 0;
static IRAM_ATTR uint32_t FadeStart = 0;
static IRAM_ATTR uint32_t FadeTimer = 0;
static bool FadeActive = false;
volatile bool Driver_FadeEnabled = true;
volatile uint8_t Driver_FadeLength = 3;

static uint8_t Driver_CurLoop = 0;

static uint8_t DacLastValue = 0;
static bool DacTouched = false;
static uint8_t opn2_regs_dedup[256*2];

static bool Driver_BlockOpn2TestReg = false;

static bool opn2_on_opna_mode = false;

static bool reset_flag = false;

#define min(a,b) ((a) < (b) ? (a) : (b)) //sigh.

void Driver_ResetChips(bool force);
void Driver_Sleep(uint32_t us);

static spi_dev_t *spihw;
static inline void Driver_Output() { //output data to shift registers
    //based on http://esp32.io/viewtopic.php?p=6271&sid=c5defe04bb681fac2ae514139f01cb49#p6271
    spihw->data_buf[0] = Driver_SrBuf[0] | (Driver_SrBuf[1]<<8);
    spihw->cmd.usr = 1;
    while (spihw->cmd.usr);
}

static uint32_t map(uint32_t x, uint32_t in_min, uint32_t in_max, uint32_t out_min, uint32_t out_max) {
  return (x - in_min) * (out_max - out_min) / (in_max - in_min) + out_min;
}
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

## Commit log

2018-07-14 add sound chip driver
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2018-07-14 add i2c and io expander interrupt pin defs
2018-07-15 fix eventgroups, remove testing stuff
    [driver.c]
2018-07-15 fix ioexpander key reading and add litle test
    [ioexp.c]
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2018-07-16 move pins.h into main/include - fixes component compile
    [pins.h]
2018-07-16 remove oled references from pin defs
2018-07-17 say hewwo to KeyMgr 🎉
2018-07-17 i2cmgr: get rid of settle time
2018-07-28 add power and amp control to ioexp
2018-07-28 driver: bring up to date with vgm changes
2018-07-31 say hewwo to BatteryMgr !! pretty basic at this point
2018-07-31 IoExp: only warn on failing to seize bus while polling
    [ioexp.c]
2018-07-31 Driver: add basic dacstream support
2018-08-09 ioexp: add charge status reading
2018-08-09 key: add poweroff/reset upon holding back
2018-08-24 driver: cleanly stop dacstreams upon reaching end (dependent on length mode)
2018-09-30 ioexpander: attempt to fix stuck keys? mcp23017 bug ??
    [ioexp.c]
2018-10-01 driver: 50-75% speed boost!
2018-10-07 driver: update to work with new loader, other improvements
2018-10-30 driver: faster reset, separate cpu counters
    [driver.c]
2018-11-04 driver: properly reset dacstream stuff upon starting
    [driver.c]
2018-11-06 driver: initial value output cleanup
2018-11-14 driver: use a status flag to ack resets
    [driver.c]
2018-11-16 ioexp: fix race condition
    [ioexp.c]
2018-11-16 driver: remove this debug message, we don't really care
2019-04-05 driver: fix errors on dacstream start
    [driver.c]
2019-04-09 fix psg frequency behavior to match sega vdp (sonic has hihats now!!)
    [driver.c]
2019-04-10 driver: correct psg frequency fix check
    [driver.c]
2019-05-13 add enclosure and pcb directories, and descriptions.
2019-06-10 yeet led stuff from ioexp
2019-06-11 disable status led stuff for now
2019-06-11 yeet amp power control stuff
2019-06-16 ioexp: more fixes for rev.2 hardware
    [ioexp.c]
2019-06-17 i2c: increase bus clk to 400khz now that the ltc6904s are gone
2019-06-27 add a method to attempt to clear a stuck i2c bus to i2cmgr. this actually exists in the internals of esp-idf's i2c master driver, but it's not exposed for whatever reason...
    [i2c.c]
2019-07-01 driver: attempt to fix occasional missed psg writes
    [driver.c]
2019-07-01 add driver side of channel led stuff. needs a lot of cleanup
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2019-07-06 add source file for front panel pcb silkscreen
2019-07-06 add front panel pcb/schematic files
    [frontpanel-new.brd, frontpanel-new.sch]
2019-07-06 add front panel board images
2019-07-08 wrap up chip resets into a function
    [driver.c]
2019-07-14 fix poweroff time
2019-07-14 add new esp32-derived clock stuff
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2019-07-14 add battery monitoring stuff to ioexp
2019-07-14 poll keys more often - sometimes interrupts get missed, this should help mask that
    [ioexp.c]
2019-07-14 clean up batterymgr a bit
2019-07-15 driver: reset chips upon end of music
    [driver.c]
2019-07-15 hook up user leds - just hardwired to sd card reads for now
2019-07-18 driver: actually use the finished flag
2019-07-18 driver: yeet unused var
2019-07-22 reorder leds in leddrv
2019-07-22 update led stuff in driver
2019-07-22 probably fix some channelmgr issues
    [channels.c]
2019-07-23 driver: make badly trimmed vgms not make ugly noises upon track start!
    [driver.c]
2019-07-26 fix dacstream length mode 1
    [driver.c]
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2019-07-27 make crash screen actually readable
    [main.c]
2019-07-27 driver: comment the psg/2612 write modification stuff a bit better.
2019-07-27 driver: shut psg up first upon reset (the difference here is basically inaudible)
    [driver.c]
2019-07-29 driver: fix setting leds for dac enable register
    [driver.c]
2019-07-30 add log stuff to clkmgr, even though it doesn't log anything at all (yet...)
    [clk.c]
2019-07-30 driver: force pan/atten registers upon start
2019-08-01 driver: actually read the psg write from the right array offset...
2019-08-30 ioexp: power on unless we explicitly set it off
2019-09-11 driver: tweak psg timing yet again...
2019-09-20 driver: give back some cpu while waiting. this might let us split some tasks between both cores...
2019-09-20 more reasonable led brightness
2019-09-20 batterymgr: very hacky poweroff upon holding A
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2019-09-21 fwupdate: avoid flash write loop
    [main.c]
2019-09-22 fix lcd writes when block size > 1920 pixels
    [lcddma.c]
2019-09-22 driver: catch 32x writes. this allows some 32x tracks to play, minus pwm of course
2019-09-23 log coredumps to sdcard
    [partitions.csv]
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2019-10-04 driver: make psg frequency fix optional
2019-10-04 add defines for pcm sbufs, in case they're ever used...
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2019-10-05 make ignoring zero-sample loops optional
2019-10-10 player: reset chips upon stopping track. helps get rid of some of the noise between tracks on ym2612
2019-11-06 move all disk access to one led
2019-11-07 Revert "drive shift registers faster on desktop ver"
    This reverts commit 844df493369d14e5586357cd985c79f04b5c0268
    [driver.c]
2019-11-13 Revert "move vgm and pcm queues to new ringbufs"
    This reverts commit cd89b417657e2b99209c767ae3ad00316f2f3d26
    [driver.c]
2019-11-14 fix startup progress bar glitch
    [main.c]
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2019-11-15 make lcddma actually use dma, and set up double vdb
2019-11-15 driver: don't spam dacstream under warnings
2019-11-21 fix crashes during coredump copying or fwupdate
    [main.c]
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2019-12-05 just switch hal to desktop by default for now
2019-12-07 Revert "slightly prettier boot"
    This reverts commit 1d7b7b43a0e28e444bcbb53f2ee1dc669dd7c7e9
    [main.c]
2019-12-08 mafipulate partition table
    [partitions.csv]
2019-12-15 don't attempt power or backlight control on desktop hw - faster boot
2019-12-21 lcddma hackery to fix crashes during flash access
    [lcddma.c]
2019-12-24 fix crash for vgms without total sample count specified
2019-12-24 fix scrub bar positions upon track start
2019-12-30 leddrv: let other stuff set brightness
2019-12-30 driver: fix hellacious psg noise on startup when force mono is enabled
    [driver.c]
2019-12-30 options: fix setting loop count for current track
2020-01-03 hook up zero sample loop option
2020-01-11 driver: ti/sega psg "periodic" noise shift reg incompatibility workaround
    [driver.c]
2020-01-11 main: init leddrv before card so leds are less floaty
2020-01-19 initial support for new megamods in driver
2020-01-19 display currently detected megamod upon boot
2020-01-19 display the actual sdcard error on boot
    [main.c]
2020-01-23 fix opna megamod detection upon boot
    [main.c]
2020-01-27 fix muting when megamod in use
    [driver.c]
2020-01-28 driver: improve opna led stuff
2020-01-31 player: fix playback of compressed files with normal vgm extension
    [driver.c]
2020-02-02 driver: force mono support for opna
2020-02-04 fix opna pcm regression
    [driver.c]
2020-02-09 driver: fix timing for dacstream writes on opna (used for ssgpcm)
    [driver.c]
2020-02-13 driver: fix opna ssg muting
    [driver.c]
2020-03-13 driver: fix opna muting on opn tracks
    [driver.c]
2020-03-21 Add note about macOS/BSD serial device paths
2020-03-21 Fix options-category clamping
2020-04-12 improve channel status leds on OPNA
2020-04-12 driver: keep track of ssg level on opn as well
2020-04-12 driver: restore cpu usage tracking
2020-04-12 leddrv: don't apply brightness LUT on user leds
2020-04-12 make user leds actually user selectable
2020-04-13 driver: alloc command queue buf on boot
2020-04-14 driver: use FromISR queue functions here as well
2020-04-24 add WIP screenshot support screenshots are saved to .mega on the sd card, screenXX.tga where XX is in hex be aware that the sequence number is not saved, so rebooting will cause existing screenshots 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
    [lcddma.c]
2020-04-27 turn off leds for muted fm channels (fixes #36)
    [channels.c]
2020-04-29 remove old enclosure and pcb directories
    [frontpanel-new.brd, frontpanel-new.sch]
2020-05-01 filebrowser: fix names getting cut off
2020-05-08 prevent scrub bar from jumping to start of loop at track end
2020-06-14 don't duplicate led writes, let channelmgr do all the updates
2020-06-14 pulse-stretch short KONs in channelmgr, optimize
    [channels.c, driver.c]
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2020-06-14 allow holding B on powerup to see boot log
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2020-06-19 commit missing files for pitch
2020-06-20 fix key repeat on pitch control
2020-06-20 fix looping when loop count decreased during playback of later loops
    [driver.c]
2020-06-28 fix rare incorrect scrub bar position on nowplaying
    [driver.c]
2020-06-28 fix hitches on tracks that write to game gear psg registers
    [driver.c]
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2020-08-29 Fix PSG noise regressions caused by fading support
    [driver.c]
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2020-09-03 Fix incorrect scrub bar position after track change while nowplaying UI not visible
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2020-09-07 Fix User LED regression
    [leddrv.c]
2020-09-12 Fix wrong LED state caused by invalid writes to KON reg
    [driver.c]
2020-09-18 Hopefully fix PSG timing issues for good
    [clk.c, driver.c]
2020-10-03 Correct dacstream timing at pitch != 100%
    [driver.c]
2020-10-03 Fix clock calculations for disabled chips
    [clk.c]
2020-10-09 Rename the LED option to be a bit more fitting
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2020-10-15 Fix options screen back button
2020-10-24 Fix rare too-long psg writes
    [driver.c]
2020-10-25 Add megapacker.pl script to create .mgu updater files
    This is a relatively simple Perl script that takes app and/or updater
    ESP32 .bin image(s) and packs them into the .mgu format that is expected
    by the MegaGRRL firmware when initiating firmware updates from the File
    Browser.
    Example usage, for an app-only update on the (d)esktop version:
    perl utils/megapacker.pl --app=firmware/build/megagrrl.bin --hw=d --outfile=megagrrl.mgu
    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
2020-10-25 Don't truncate app_elf_sha256 when parsing esp_app_desc_t
    This isn't currently used except to output debug-esque information about
    the parsed header.
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2020-11-05 Fix: Restoring temporary clock double-takes mutex
    [clk.c]
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2020-12-23 Fix GCC warnings
    Some were found with the addition of -Wshadow.
    Mostly just casting (e.g. dropping volatile), but also some unused
    variables were commented out, and an out of bounds array access was
    fixed in Ui_SoftBar_Setup().
    Pragmas were added to silence strict-aliasing warnings, and the affected
    macros were reformatted for better readability.
    With the addition of these changes, no warnings are seen during the
    firmware build.
    [battery.c, driver.c, i2c.c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]
2020-12-24 Bump esp-idf to v3.3.4
    Released 2020/09/24.
    A few symbols in the sdkconfig have changed, but the original SPI
    patches still apply cleanly. The new symbols were left at their default
    values.
2021-02-08 Revert specifically bus dedup for now.
    [driver.c]
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2021-03-20 Fix playback issues on Rocket Knight Adventure/Comix Zone VGMs from Project2612
    [driver.c]
2021-03-20 Just let writes to registers in wrong bank fall through
    [driver.c]
2021-04-19 Fix log level update on boot
    [main.c]
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2021-05-18 Fix erroneous loglevel change at boot
    [main.c]
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2021-07-12 Fix support for first SN76489 in dual-chip vgms
    [driver.c]
2021-11-06 Fix #90 - invalid clock check on OPLL+DCSG MegaMod
    [driver.c]
2021-11-06 Use non-reversed data bus for DCSG on Denjhang's OPLL+DCSG mod
    [driver.c]
2021-11-06 Fix issues from 373f940692414819231a8012934190e8cc73d76d
    [driver.c]
2022-01-31 Correct DCSG frequency latch handling - fixes #106
    [driver.c]
2023-01-01 Clamp displayed CPU usage in debug screen - fixes #104
2023-11-04 Deduplicate chip resets - removes one of the clicks between tracks
    [driver.c]
2023-11-04 Driver: restore early resets
    [driver.c, main.c]
2024-04-08 Add support for inverted ILI9341 displays
    [lcddma.c]
2024-08-20 UserLed: Fix incorrect LEDs under certain combinations of settings
2024-08-20 Nowplaying: Show loading spinner while track decompressing, etc
2025-02-14 Player: Don't reopen file upon restarting currently playing track
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2025-06-16 UserLed: Slight improvement to chip write LED behavior
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

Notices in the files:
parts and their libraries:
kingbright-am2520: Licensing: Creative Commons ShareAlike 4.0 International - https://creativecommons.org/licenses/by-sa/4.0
